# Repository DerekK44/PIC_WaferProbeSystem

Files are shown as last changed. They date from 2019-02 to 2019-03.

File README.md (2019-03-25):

# PIC_WaferProbeSystem
Python libraries for communicating with optical test equipment, as well as a GUI front-end for automating photonics measurements. Also included are hardware schematics (drawings, CAD files, and assemblies) for a 150mm wafer-scale automated grating coupler test setup.  The measurement system allows for manual positioning of two fibers or fiber arrays each with 6-DOF (XYZ, pitch, roll, yaw) over a wafer with rotation and precision motorized XY stages (150mm travel & 0.1um step sizes in each direction)

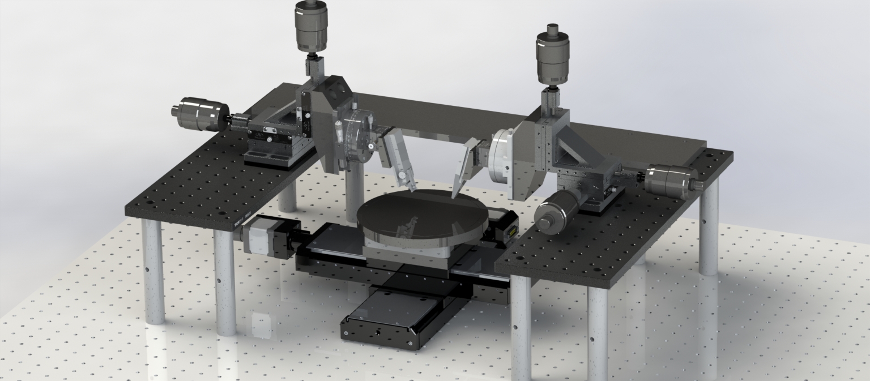
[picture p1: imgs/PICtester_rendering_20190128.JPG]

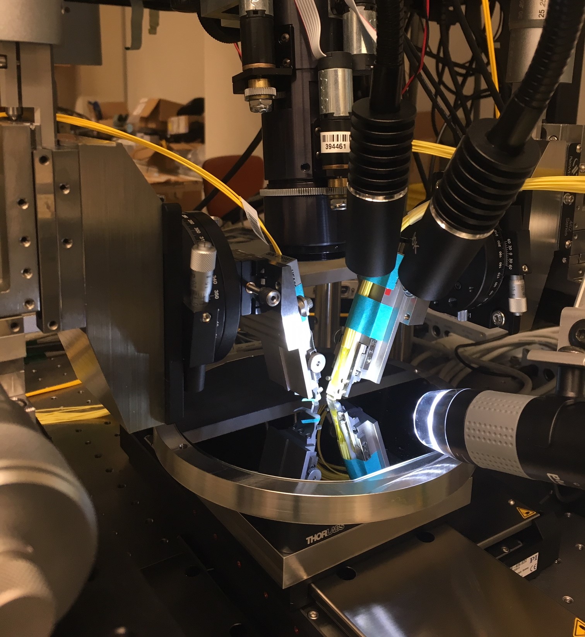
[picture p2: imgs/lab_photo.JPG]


**Softare usage**: running PUMA_gui.py starts the user interface.  Physike Instrumente stages and AQ2140 photodetector module should be turned on.

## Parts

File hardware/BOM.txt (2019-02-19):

Bill of Materials
Copyright Derek M. Kita, 2019.

==================================================
Custom components for the alignment setup
Using Plethora for CNC milled steel pieces
1/2" thick iron (magnetic) board cut on waterjet
==================================================

fiber holder adaptor, quantity 2, 303 steel
XYZ to rotation adaptor, quantity 2, 303 steel

wafer chuck, quantity 1, 303 steel
rotation stage adaptor, quantity 1, 303 steel

In total, 6 machined parts

==================================================
Thorlabs + Newport components
==================================================

Thorlabs PR01 2x
Thorlabs PR01A 2x
Thorlabs GN2 2x
Thorlabs RS6 8x
Thorlabs MB618 2x
Thorlabs HFV002 2x
Thorlabs RP03 1x
Thorlabs SLH1 2x

Newport 462-XYZ-M 1x(right-hand)
Newport 462-XYZ-LH-M 1x (left-hand)
Newport HR-1 6x (for 0.1um sensitivity)
Newport 9021-M 2x (to lift the XYZ stage up by ~6mm)

==================================================
Physike Instrumente Stages
Linear stages with 150mm travel, 0.1um step size
==================================================

PI M-406.6DG stages 2x
PI C-863.11 DC motor controller 2x

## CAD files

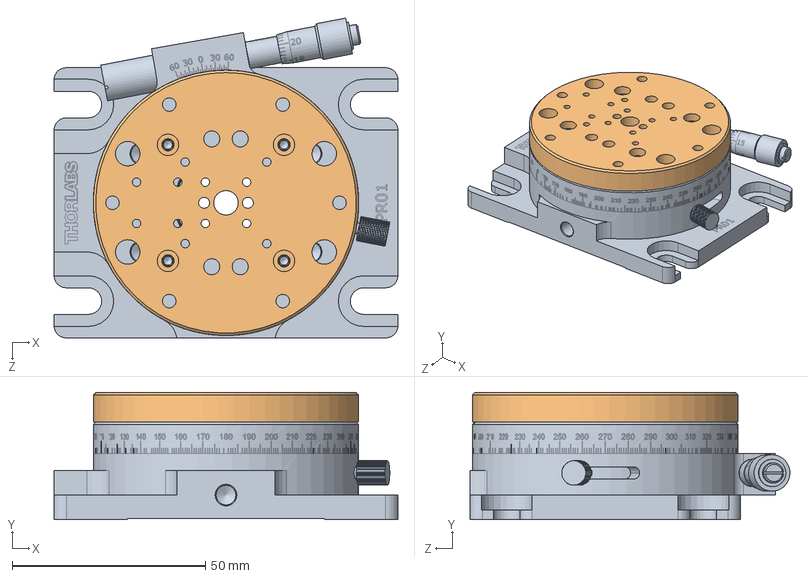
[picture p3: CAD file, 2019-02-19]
hardware/purchased components/PR01 + adaptor.SLDASM
88.9 x 32.9 x 82.7 mm
PR01-Solidworks
PR01A-Solidworks

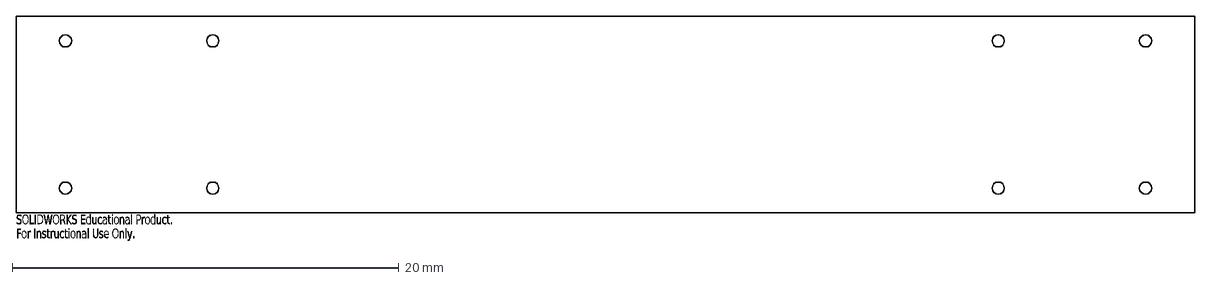
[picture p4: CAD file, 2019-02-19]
hardware/custom parts/Iron_board_probe_station.DXF
SOLIDWORKS Educational Product.
For Instructional Use Only.

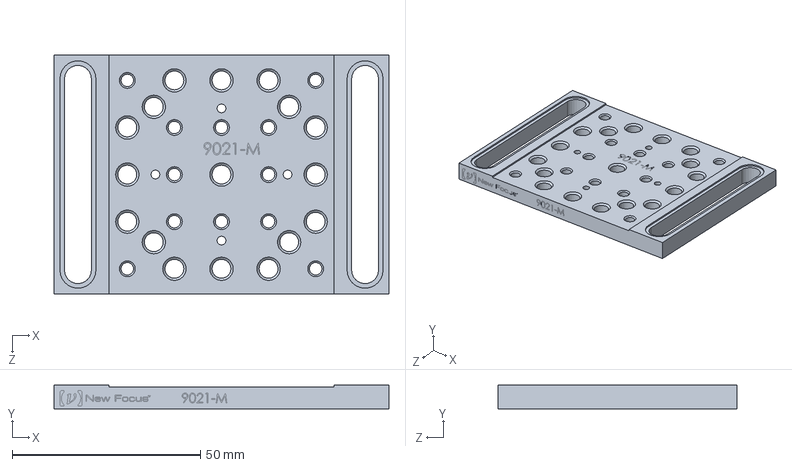
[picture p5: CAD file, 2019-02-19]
hardware/purchased components/9021-M.SLDPRT
88.9 x 6.35 x 63.5 mm

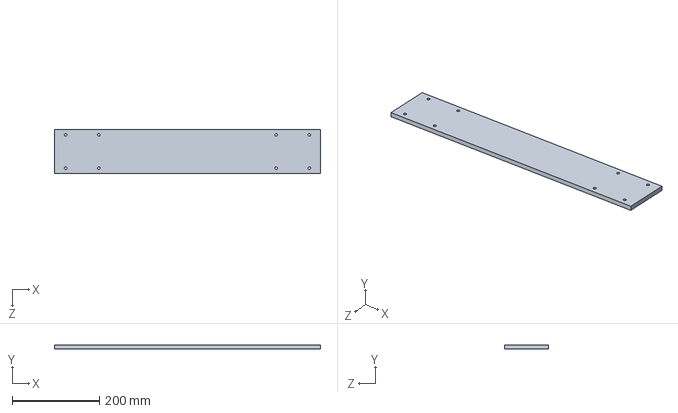
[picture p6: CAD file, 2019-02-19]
hardware/custom parts/iron board for electrical probing.SLDPRT
609.6 x 9.53 x 101.6 mm

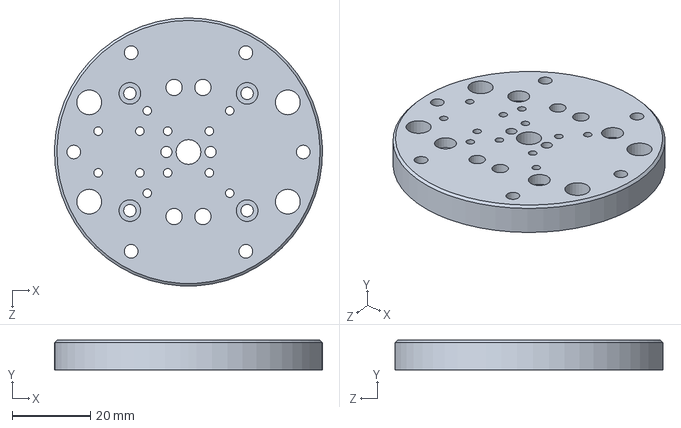
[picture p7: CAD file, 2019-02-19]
hardware/purchased components/PR01A-Solidworks.sldprt
68.5 x 7.62 x 68.6 mm

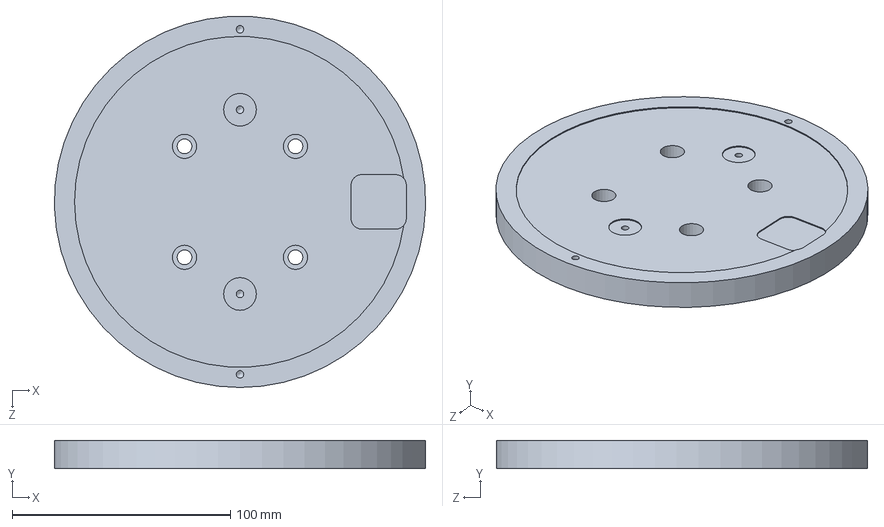
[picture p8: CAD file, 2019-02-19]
hardware/custom parts/Wafer chuck.SLDPRT
169.9 x 13.0 x 169.9 mm

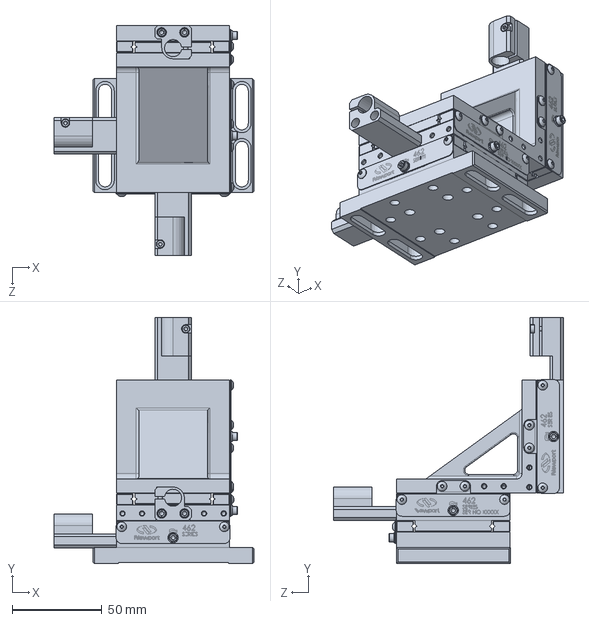
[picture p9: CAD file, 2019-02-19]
hardware/purchased components/462-XYZ-M.sldprt
111.3 x 137.0 x 128.0 mm

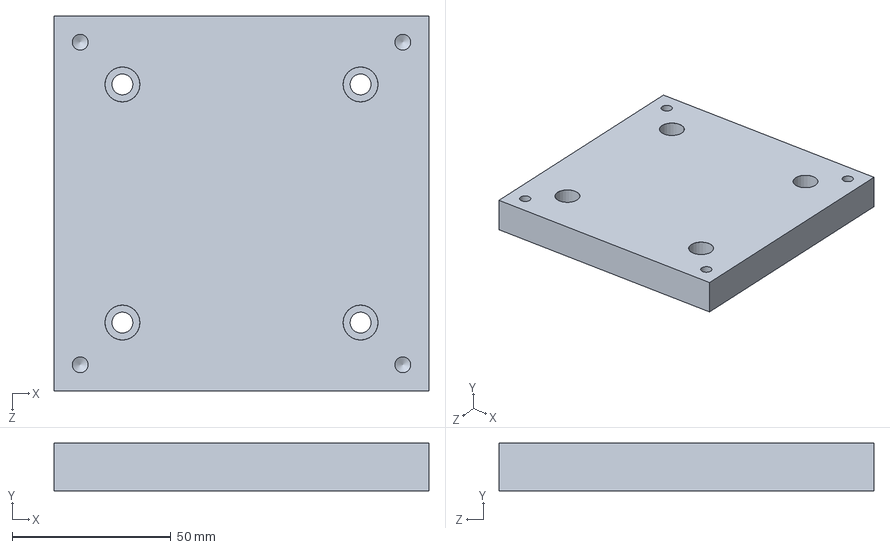
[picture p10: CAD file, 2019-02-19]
hardware/custom parts/rotation stage adaptor.SLDPRT
118.1 x 15.0 x 118.1 mm

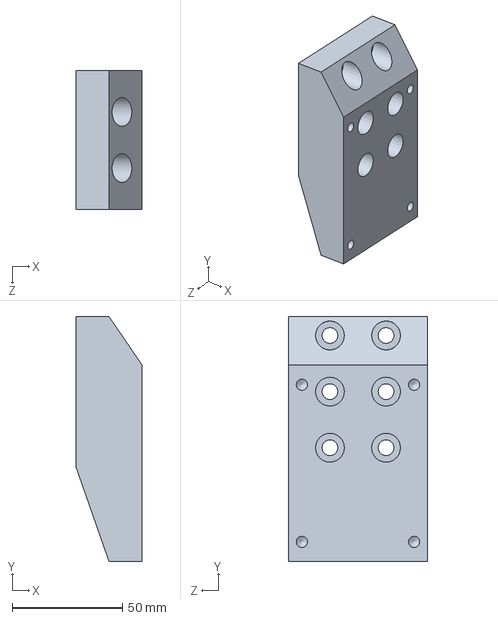
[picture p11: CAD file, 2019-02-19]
hardware/custom parts/XYZ_to_rotation_adapter.SLDPRT
30.0 x 110.9 x 63.0 mm

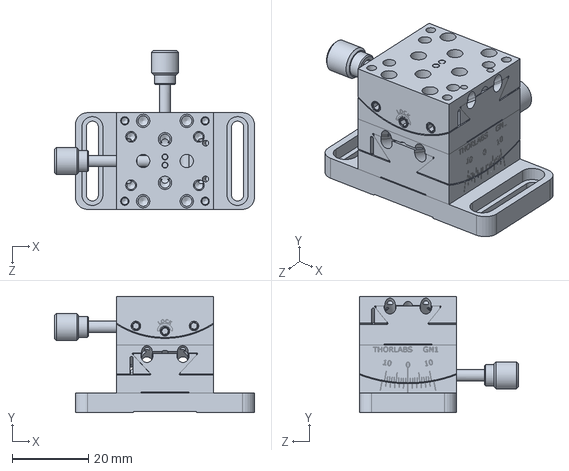
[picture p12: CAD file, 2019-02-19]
hardware/purchased components/GN2-Solidworks.sldprt
52.5 x 30.5 x 41.7 mm

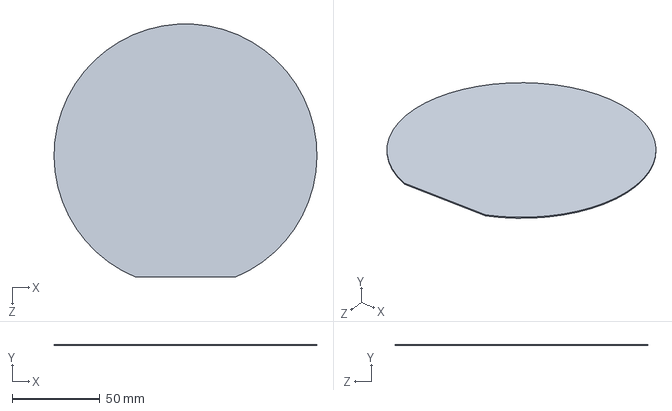
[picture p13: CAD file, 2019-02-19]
hardware/custom parts/Si_wafer.SLDPRT
150.0 x 0.675 x 144.1 mm

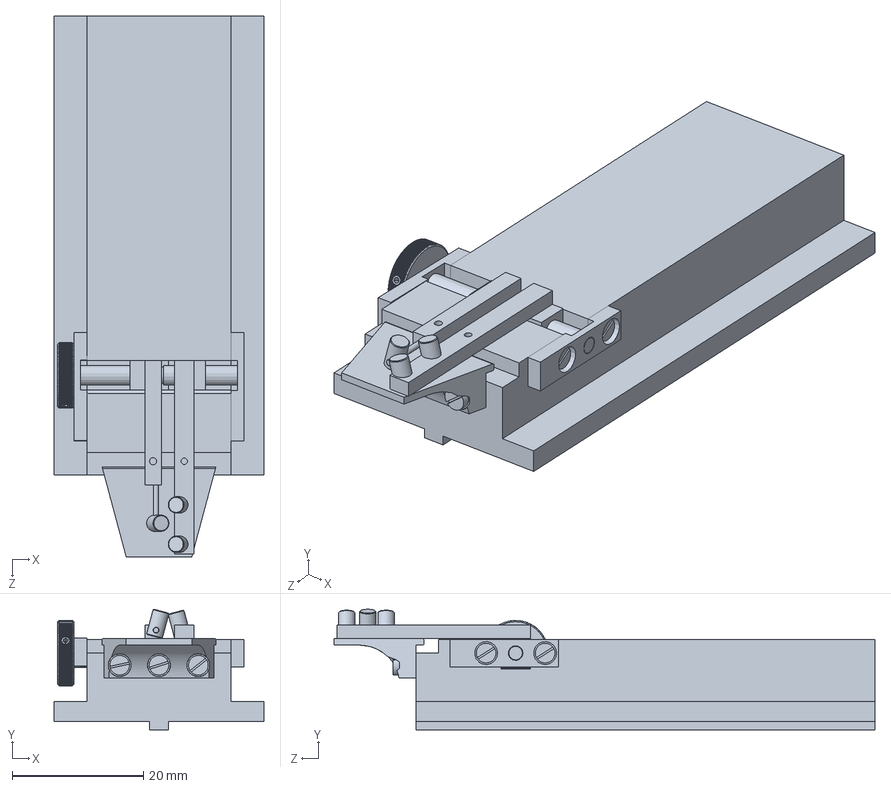
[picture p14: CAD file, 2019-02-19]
hardware/purchased components/HFA001-Solidworks.sldprt
32.0 x 18.4 x 82.5 mm

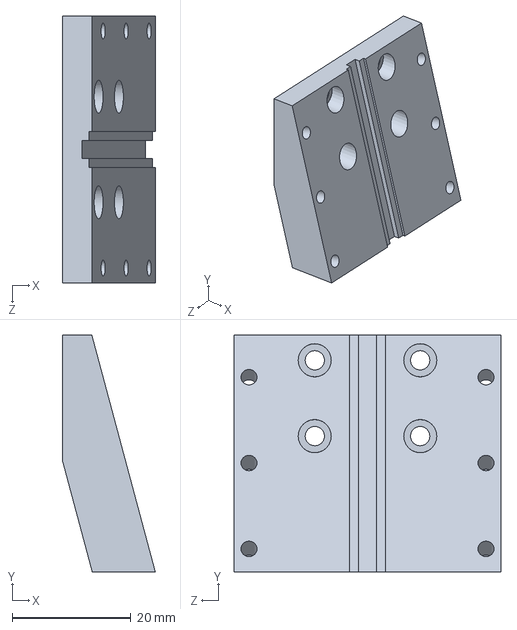
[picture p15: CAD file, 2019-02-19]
hardware/custom parts/fiber holder adaptor.SLDPRT
15.6 x 40.0 x 45.0 mm

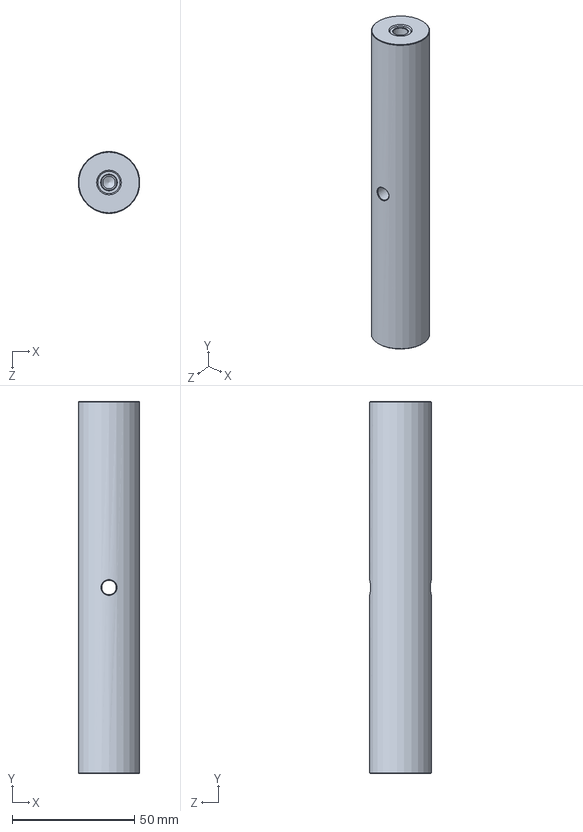
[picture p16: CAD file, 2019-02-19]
hardware/purchased components/RS6-Solidworks.sldprt
25.2 x 152.4 x 25.4 mm

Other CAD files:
hardware/purchased components/MB618-Solidworks.sldprt
hardware/purchased components/HFV002-Solidworks.sldprt
hardware/purchased components/HR-1.SLDPRT
hardware/purchased components/GN2- no base.SLDPRT
hardware/custom parts/Wafer chuck.STL
hardware/custom parts/XYZ_to_rotation_adapter.STL
hardware/custom parts/fiber holder adaptor.STL
hardware/custom parts/rotation stage adaptor.STL
hardware/purchased components/M-406.62S.SLDPRT
hardware/purchased components/Magnetic board for electrical probing.SLDDRW

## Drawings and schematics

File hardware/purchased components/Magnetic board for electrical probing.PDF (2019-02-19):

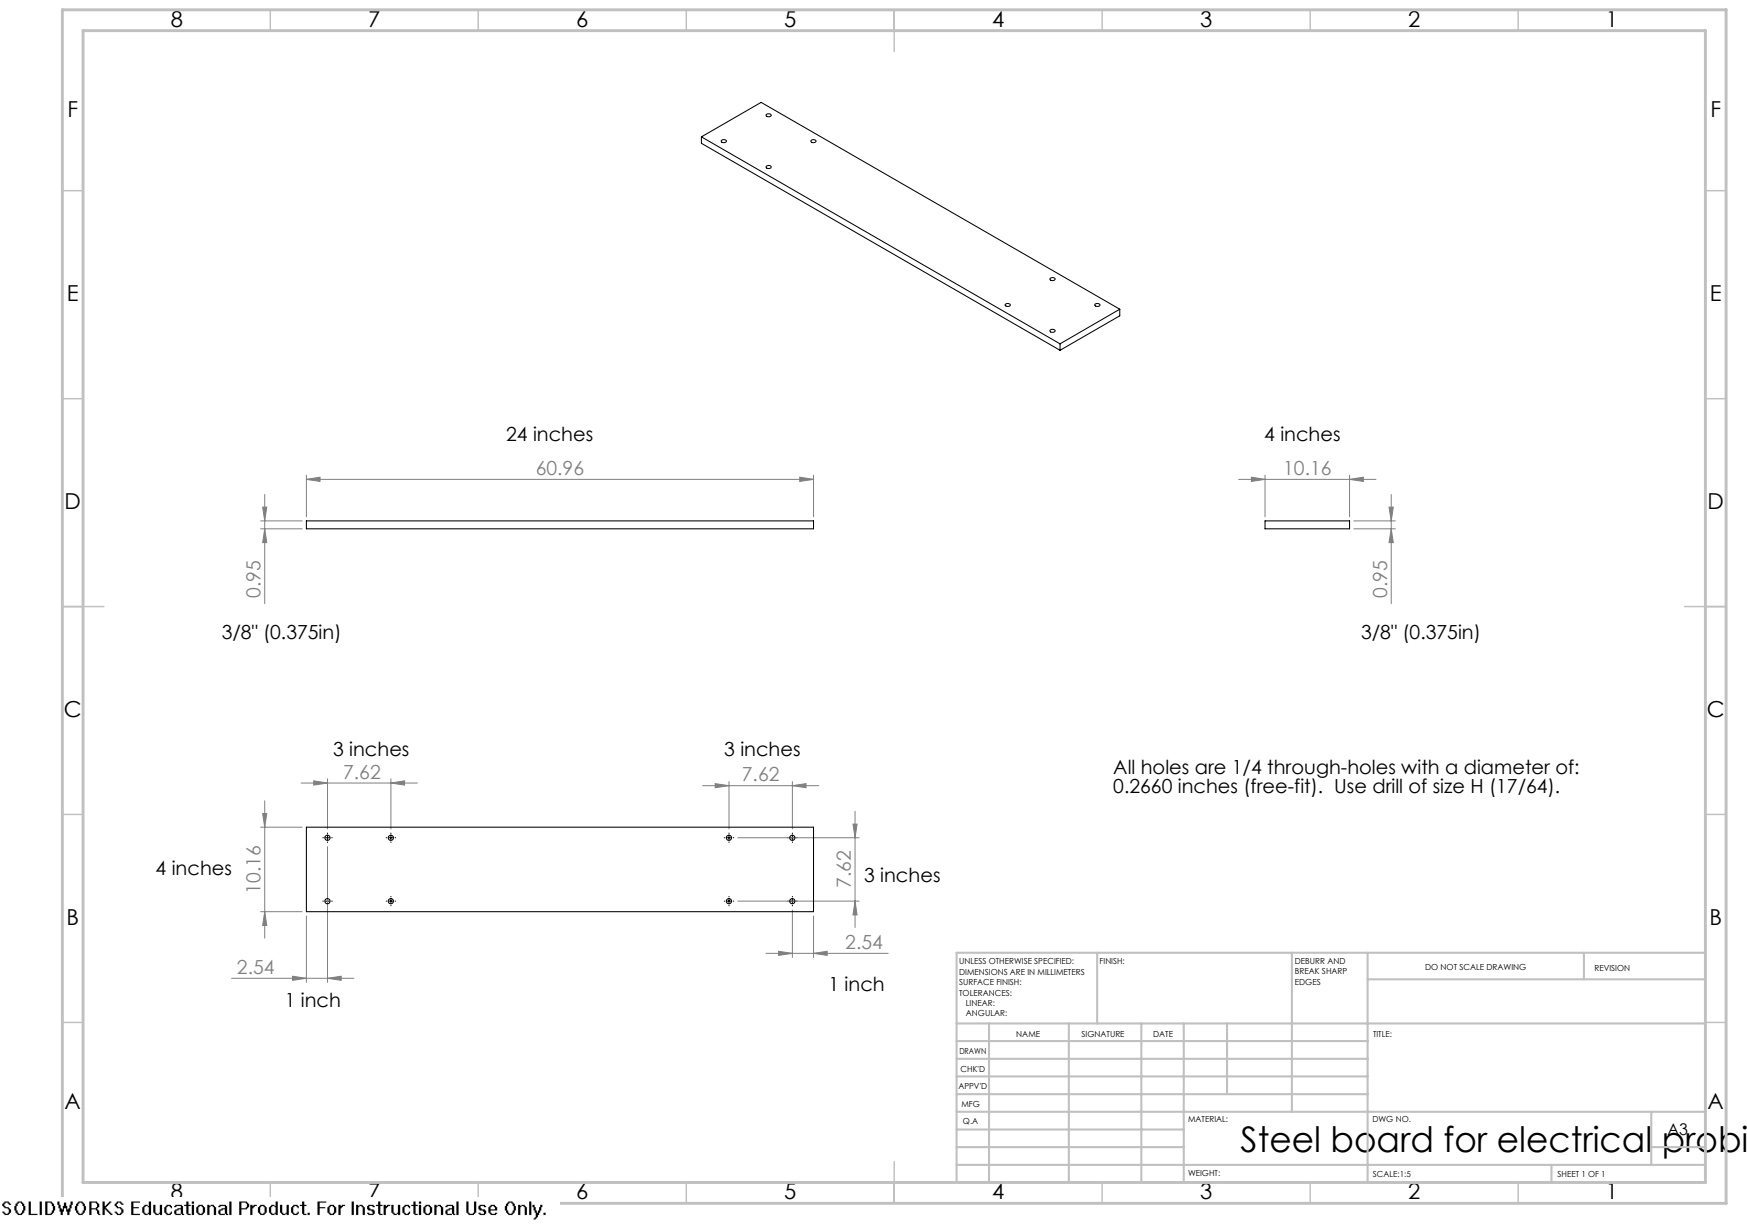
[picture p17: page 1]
3 inches; 1 inch; 24 inches; 4 inches; FINISH:; DEBURR AND; BREAK SHARP; DO NOT SCALE DRAWING; REVISION; SCALE:1:5; SHEET 1 OF 1

All holes are 1/4 through-holes with a diameter of:
0.2660 inches (free-fit). Use drill of size H (17/64).

UNLESS OTHERWISE SPECIFIED:
DIMENSIONS ARE IN MILLIMETERS
SURFACE FINISH:
TOLERANCES:
LINEAR:
ANGULAR:

NAME | SIGNATURE | DATE | | | | TITLE:

DRAWN
CHK'D
APPV'D
MFG
Q.A | | | | MATERIAL: | DWG NO. | A3

Steel board for electrical probing

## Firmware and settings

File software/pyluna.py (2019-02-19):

# -*- coding: utf-8 -*-
"""
Created on Wed Sep 12 19:54:26 2018

@author: PUMA
"""
import visa
import matplotlib.pyplot as plt
import time
import numpy as np
import pandas as pd

class Luna:
    
    def __init__(self, GPIB='GPIB0::8::INSTR'):
        self.startup_luna(GPIB)
        
        self.min_loss = [] #empty until measured for the first time
        self.max_loss = []
        self.wl_list = []
        
    def close(self):
        self.luna.close()
        
    def startup_luna(self, GPIB):
        rm = visa.ResourceManager()
        self.luna = rm.open_resource(GPIB)
        
        self.luna.timeout = 120000
        
        print(self.luna.query("*IDN?"))

        while self.luna.query("SYST:WARM?") != '1':
            print("LUNA system is still warming up...")
            time_remaining = float(luna.query("SYST:WTIM?"))
            print(str(time_remaining)+" minutes remaining")
            time.sleep(time_remaining*60.0)
        print("Luna is at operating temperature.")
        
        #Turn on the laser
        self.luna.write("SYST:LASE 1")
        if self.luna.query("SYST:LASE?")=='1':
            print("Luna laser is ON")
        else:
            print("Warning! Luna laser is OFF.")
            
#        self.set_source_wavelength(1550.0)
#        self.turnon_light_source()
#        print("Luna is on and at 1550.0 nm")
        
    def configure_scan_parameters(self, 
                                  center_wl=None, 
                                  start_wl=None,
                                  scan_range=None
                                  ):
        """ Configure the scan parameters
        center_wl = center wavelength in NANOMETERS
        start_wl = start wavelength in NANOMETERS
        """
        if center_wl != None:
            self.luna.write("CONF:CWL "+str(center_wl))
            
        if start_wl != None:
            self.luna.write("CONF:STAR "+str(start_wl))
            
        if scan_range != None:
            self.luna.write("CONF:RANG "+str(scan_range))
            
    def find_DUT(self):
        """ Automatically find the DUT and set it
        """
        self.luna.write("CONF:DUTL")
        
    def get_DUT(self):
        return self.luna.query("CONF:DUTL?")
    
    def set_source_wavelength(self, wavelength):
        """ Sets the luna to "source" mode and gives it the wavelength below
        wavelength should be specified in NANOMETERS
        """
        self.luna.write("CONF:WAVE "+str(wavelength))
    
    def turnon_light_source(self):
        """ Should first set the source wavelength using set_source_wavelength
        """
        self.luna.write("CONF:SOUR 0")
    
    def scan(self, plot=True, meas_type=11):
        """ Performs a scan using the previously configured values.
        
        By default, meas_type is set to "11", which means that the min/max loss
        will be returned and plotted.
        
        Returns an array with the measured data and plots the values
        """
        self.luna.write("CONF:SOUR 1") #Close the source switch
        
        if self.luna.query("SYST:RDY?")=='1':
            print("System ready and scanning...")
            self.luna.write("SCAN")
        else:
            print("Warning! System is not ready for a scan...")
            print("SYST:RDY? status = "+str(self.luna.query("SYST:RDY?")))
            return None
        
        systerr = self.luna.query("SYST:ERR?")
        if systerr !='0':
            print("Warning!  System error occured during scan.")
            print("Luna error code: "+str(systerr))
            description = self.luna.query("SYST:ERRD?")
            print("Description: "+str(description))
            
        output_size = int(self.luna.query("FETC:FSIZ?"))
        output = self.luna.query("FETC:MEAS? "+str(meas_type))
        meas_data = [float(s) for s in output.split('\r')[:-1]]
        min_loss, max_loss = meas_data[0:len(meas_data)//2], meas_data[len(meas_data)//2:]
        
        freq_data = self.luna.query("FETC:FREQ?").split(",")
        freq_list = [float(freq_data[0]) - i*float(freq_data[1]) for i in range(output_size)]
        wl_list = [299792458.0/freq_list[i] for i in range(len(freq_list))][::-1]
        
        if plot==True:
            plt.figure()
            plt.plot(wl_list, min_loss, 'b', label='min loss')
            plt.plot(wl_list, max_loss, 'r', label='max loss')
            plt.xlabel("wavelength [nm]")
            plt.ylabel("loss [dB]")
            plt.show()
            
        self.wl_list = wl_list
        self.min_loss, self.max_loss = min_loss, max_loss
        
        # Return luna to source mode
#        self.turnon_light_source()
        
    def close_plot(self):
        plt.close()
        plt.clf()
        
    def save_scan_data(self, filename='data.csv'):
        df = pd.DataFrame({"wavelength [nm]" : np.array(self.wl_list),
                           "min loss [dB]" : np.array(self.min_loss),
                           "max loss [dB]" : np.array(self.max_loss)})
        df.to_csv(filename, index=False)        
        
    def query_scan_parameters(self):
        """ Prints all the scan parameters """
        print("Center wavelength = "+str(self.luna.query("CONF:CWL?")))
        print("Start wavelength = "+str(self.luna.query("CONF:STAR?")))
        print("End wavelength = "+str(self.luna.query("CONF:END?")))
        print("Scan range = "+str(self.luna.query("CONF:RANG?")))
        if self.luna.query("CONF:TEST?")=='0':
            print("Measurement type = 'reflection'")
        elif self.luna.query("CONF:TEST?")=='1':
            print("Measurement type = 'transmission'")

if __name__ == '__main__':
    luna = Luna()
    
    luna.configure_scan_parameters(center_wl=1552.0,
                                   scan_range=20.0)
    luna.query_scan_parameters()
    
    luna.scan()
    
    luna.save_scan_data(filename="data_test.csv")

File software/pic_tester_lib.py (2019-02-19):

# -*- coding: utf-8 -*-
"""
Created on Sat Sep 15 15:24:32 2018

@author: Derek Kita, 2018
"""

from __future__ import print_function
from pipython import GCSDevice, pitools
import visa
import time
import matplotlib as mpl
from mpl_toolkits import mplot3d
import numpy as np
import matplotlib.pyplot as plt
import operator
import pandas as pd

UM2MM = 0.001 #conversion between um to mm

class PICtester:
    
    def __init__(self, PD_GPIB='GPIB0::17::INSTR'):
        self.startup_motors()
        self.startup_photodetector(PD_GPIB)
        
        self.angle_offset = 0.0 #DEFAULT TO ZERO, NO ROTATION
        
        self.spiral_data = [[], [], []]
        
    def close(self):
        self.xmotor.close()
        self.ymotor.close()
        self.pd.close()

    def startup_motors(self):
        """
        Function for connecting to the PhysikeInstrumente XY stages
        
        Returns
        """
        # C-863 controller with device ID 1, this is the master device
        # C-863 controller with device ID 2
        
        master_SN = '0185500606' # serial number of the master controller (the one connected to the PC)
        CONTROLLERNAME = 'C-863.11'
        STAGES = ['M-406.6DG']  # connect stages to axes
        REFMODES = ['FRF']  # reference the connected stages
        self.axis='1' #All M-406.6DG stages are linear, meaning they only have 1 axis
        
        """Connect two controllers on a daisy chain."""
        self.xmotor = GCSDevice(CONTROLLERNAME)
        self.xmotor.OpenUSBDaisyChain(description=master_SN)
        daisychainid = self.xmotor.dcid
        self.xmotor.ConnectDaisyChainDevice(1, daisychainid)
        
        self.ymotor = GCSDevice(CONTROLLERNAME)
        self.ymotor.ConnectDaisyChainDevice(2, daisychainid)
        print('\n{}:\n{}'.format(self.xmotor.GetInterfaceDescription(), self.xmotor.qIDN()))
        print('\n{}:\n{}'.format(self.ymotor.GetInterfaceDescription(), self.ymotor.qIDN()))
        # Show the version info which is helpful for PI support when there
        # are any issues.
        if self.xmotor.HasqVER():
            print('version info:\n{}'.format(self.xmotor.qVER().strip()))
            
        print('initialize connected stages...')
        pitools.startup(self.xmotor, stages=STAGES, refmodes=REFMODES)
        pitools.startup(self.ymotor, stages=STAGES, refmodes=REFMODES)
        
        self.xmin = self.xmotor.qTMN()[self.axis]
        self.xmax = self.xmotor.qTMX()[self.axis]
        self.xcur = self.xmotor.qPOS()[self.axis]
        
        self.ymin = self.ymotor.qTMN()[self.axis]
        self.ymax = self.ymotor.qTMX()[self.axis]
        self.ycur = self.ymotor.qPOS()[self.axis]
        
        print("curpos = "+str((self.xcur, self.ycur)))
        
        """ Set the origin (center of the stage) to be (0,0) """
        self.origin = {'x':(self.xmax-self.xmin)/2.0, 
                       'y':(self.ymax-self.ymin)/2.0}
        
    def move_stage(self, xnew, ynew):
        """ Move to the new position (xnew, ynew) 
        IN UNITS OF MICRONS """
        
        #Send command to motor, accounting for origin and micron to millimeter conversion
        self.xmotor.MOV(self.axis, (UM2MM*xnew)+self.origin['x'])
        self.ymotor.MOV(self.axis, (UM2MM*ynew)+self.origin['y'])
        
        self.xcur = (UM2MM*xnew)+self.origin['x']
        self.ycur = (UM2MM*ynew)+self.origin['y']
        
        #Wait for move to complete
        pitools.waitontarget(self.xmotor, axes=self.axis)
        pitools.waitontarget(self.ymotor, axes=self.axis)
        
    def move_stage_relative(self, xmove, ymove):
        """ Move to new position with relative offset (xmove, ymove)
        IN UNITS OF MICRONS """
        
        #First account for rotation
        xmove_r = xmove*np.cos(self.angle_offset) - ymove*np.sin(self.angle_offset)
        ymove_r = xmove*np.sin(self.angle_offset) + ymove*np.cos(self.angle_offset)
        
        #Next, send command to motor, accounting for origin and micron to millimeter conversion
        self.xmotor.MOV(self.axis, (UM2MM*xmove_r)+self.xcur)
        self.ymotor.MOV(self.axis, (UM2MM*ymove_r)+self.ycur)
        
        self.xcur = (UM2MM*xmove_r)+self.xcur
        self.ycur = (UM2MM*ymove_r)+self.ycur
        
        #Wait for move to complete
        pitools.waitontarget(self.xmotor, axes=self.axis)
        pitools.waitontarget(self.ymotor, axes=self.axis)
        
    def query_position(self):
        """ Get the current position of the stages """
        motor_position = (self.xmotor.qPOS(self.axis)[self.axis], self.ymotor.qPOS(self.axis)[self.axis])
        return ((motor_position[0]-self.origin['x'])/UM2MM, (motor_position[1]-self.origin['y'])/UM2MM)
        
    def startup_photodetector(self, GPIB):
        rm = visa.ResourceManager()
        self.pd = rm.open_resource(GPIB)
        
    def parse_AQ2140_output(self, output):
        for i in range(len(output)):
            letter = output[i]
            if i==1:
                if letter=='Z' or letter=='U' or letter=='O' or letter=='R':
                    """ Wait a bit then measure again """
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
